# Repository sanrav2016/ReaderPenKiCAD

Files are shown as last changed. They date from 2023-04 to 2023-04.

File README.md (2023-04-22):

# ReaderPen KiCAD

KiCAD files for Reader Pen project. Manufacturing files for the PCB can be found here: https://github.com/sanrav2016/ReaderPenPCB.

Image of the schematic:


Some notes:
- We are using the STM32H723 microcontroller. STM is a reputable microcontroller manufacturer that dominates the commercial embedded systems market. This particular model belongs to their high-performance MCU series. The STM32H723 has a Cortex M7, and the VET6 package can run at 550MHz with 1 M flash and 564 K RAM. We have included an external 50 MHz clock. 
- We are using the TP4056 for microUSB charge control for a 3.7V 1000mAh LiPo battery.
- RGB LED for status indication
- Scan LEDs to highlight paper when reading
- The camera module in this system is the Himax HM01B0. It will not be ordered as we already have it at home from the Arducam module. A 2.8V LDO is necessarily included. 
- SWD for programming
- TRRS audio jack for speaker and mic (ADC/DAC). For simplicity no DSP is implemented.

The system will be programmed through STM32CubeIDE. Currently we are planning on using the C distributions of Tesseract and espeak, while implementing manual image processing. A demo of this concept can be found here: https://github.com/sanrav2016/ReaderPenRPiDemo.

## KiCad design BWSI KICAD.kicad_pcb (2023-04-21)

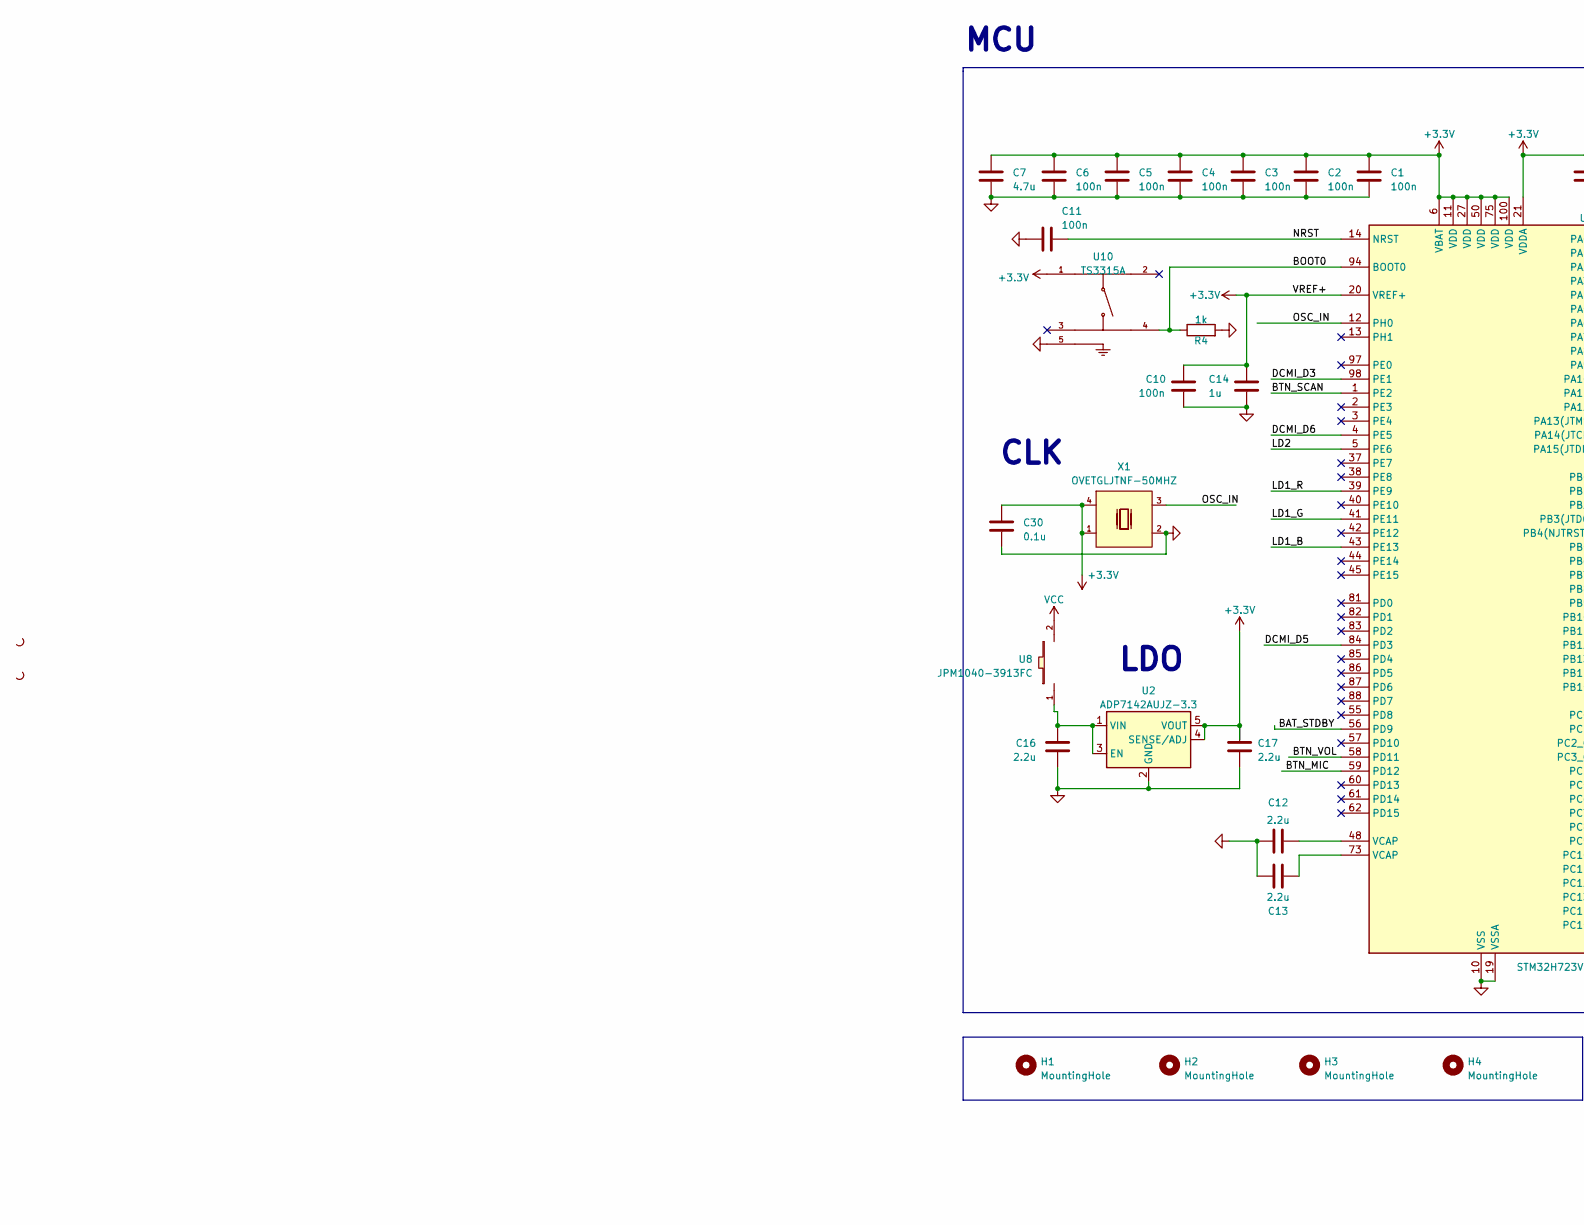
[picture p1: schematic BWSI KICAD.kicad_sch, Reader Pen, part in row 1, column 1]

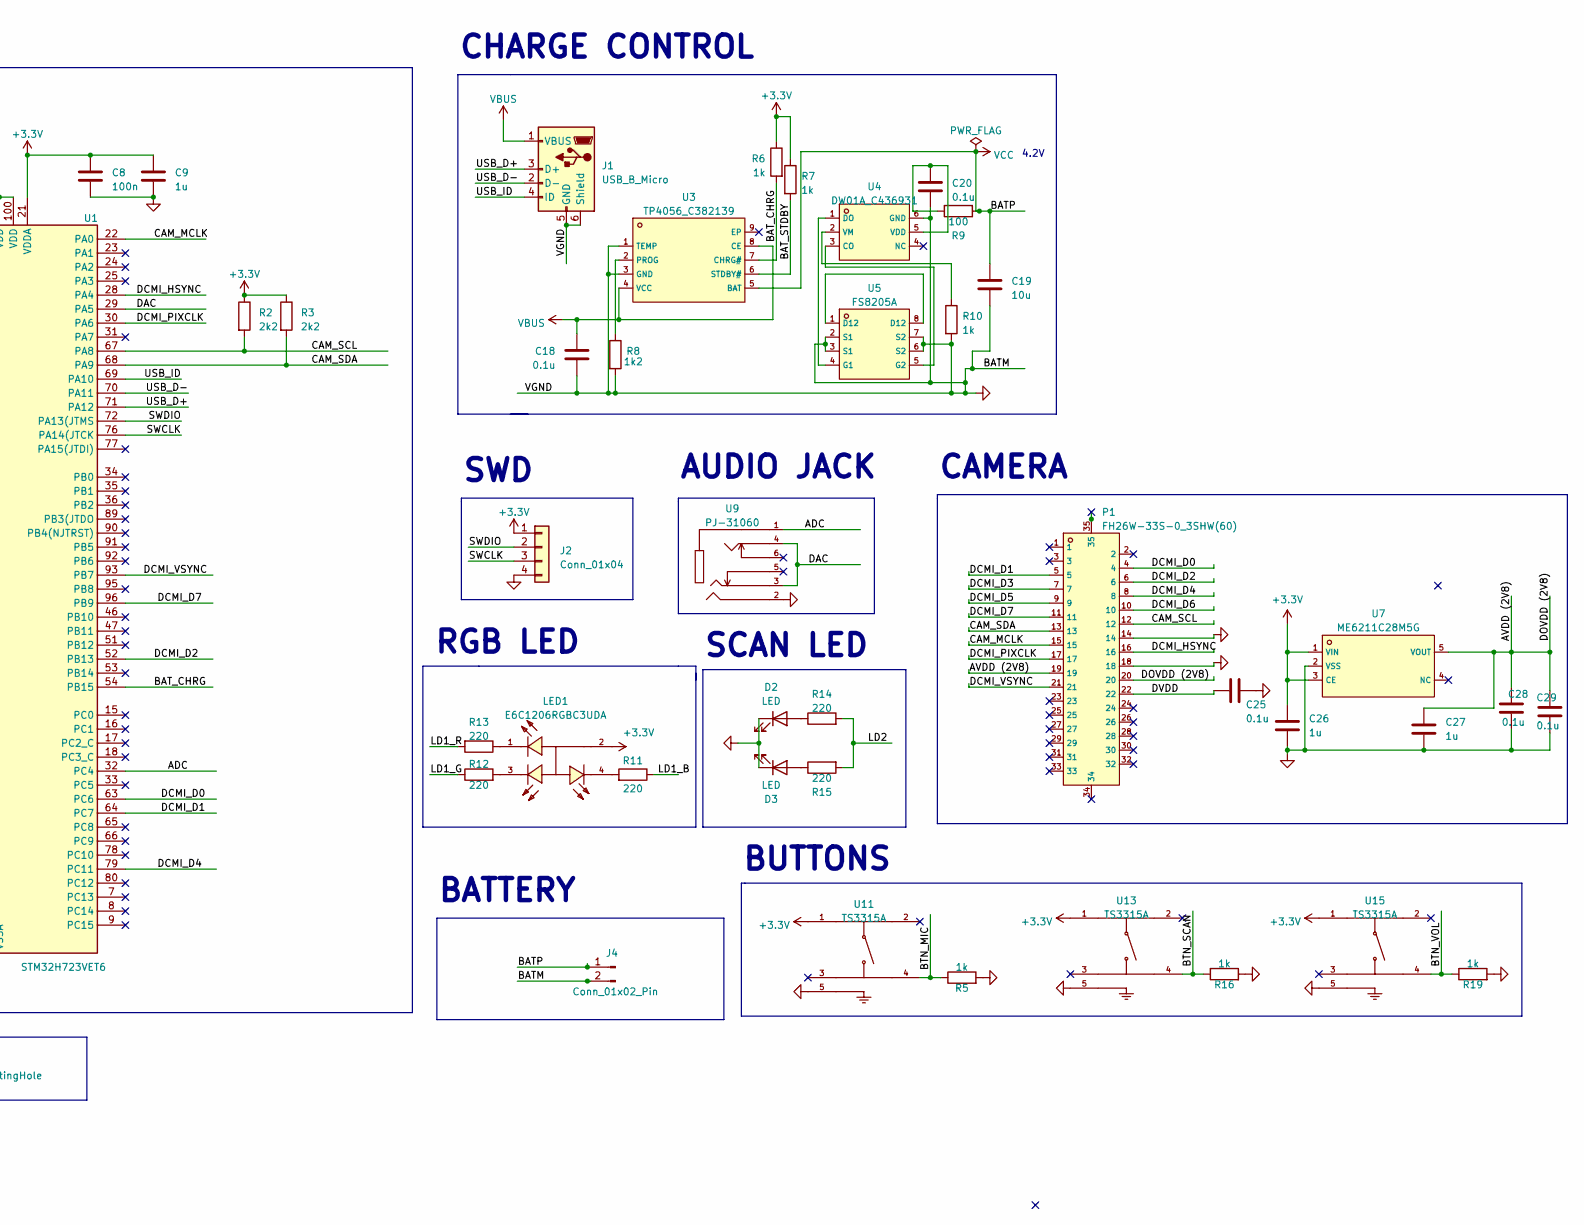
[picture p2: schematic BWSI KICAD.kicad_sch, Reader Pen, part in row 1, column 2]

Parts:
C1, C2, C3, C4, C5, C6, C8, C10, C11: 100n; C_0402_1005Metric
C7: 4.7u; C_0402_1005Metric
C9, C14, C26, C27: 1u; C_0402_1005Metric
C12, C13, C16, C17: 2.2u; C_0402_1005Metric
C18, C20, C25, C28, C29, C30: 0.1u; C_0402_1005Metric
C19: 10u; C_0402_1005Metric
D2, D3: LED; LED_0805_2012Metric
H1, H2, H3, H4: MountingHole; MountingHole_2.2mm_M2
J1: USB_B_Micro; USB_Micro-B_Molex_47346-0001
J2: Conn_01x04; SolderWire-0.25sqmm_1x04_P4.2mm_D0.65mm_OD1.7mm
J4: Conn_01x02_Pin; SolderWire-0.25sqmm_1x02_P4.2mm_D0.65mm_OD1.7mm
LED1: E6C1206RGBC3UDA; LED-SMD_4P-L3.0-W1.5-TL-FD; LCSC C375571
P1: FH26W-33S-0_3SHW(60); FPC-SMD_FH26W-33S-0.3SHW-60; LCSC C424654
R2, R3: 2k2; R_0402_1005Metric
R4, R5, R6, R7, R10, R16, R19: 1k; R_0402_1005Metric
R8: 1k2; R_0402_1005Metric
R9: 100; R_0402_1005Metric
R11, R12, R13, R14, R15: 220; R_0402_1005Metric
U1: STM32H723VET6; LQFP-100_14x14mm_P0.5mm
U2: ADP7142AUJZ-3.3; TSOT-23-5
U3: TP4056_C382139; ESOP-8_L4.9-W3.9-P1.27-LS6.0-BL-EP; LCSC C382139
U4: DW01A_C436931; SOT-23-6_L2.9-W1.6-P0.95-LS2.8-BL; LCSC C436931
U5: FS8205A; TSSOP-8_L4.4-W3.0-P0.65-LS6.4-BL-2; LCSC C16052
U7: ME6211C28M5G; SOT-23-5_L3.0-W1.7-P0.95-LS2.8-BR; LCSC C53099
U8: JPM1040-3913FC; SW-SMD_SMK_JPM1040-XXXXFC; LCSC C516063
U9: PJ-31060; AUDIO-SMD_HOOYA_PJ-31060; LCSC C2939583
U10, U11, U13, U15: TS3315A; SW-SMD_4P-L3.4-W3.4-P2.00-LS4.0_TS3315A160GF; LCSC C412367
X1: OVETGLJTNF-50MHZ; OSC-SMD_4P-L5.0-W3.2-BL_SG5032; LCSC C117891

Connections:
+3.3V: C1.1, C2.1, C3.1, C4.1, C5.1, C6.1, C7.1, C8.1, C9.1, C10.1, C14.1, C17.1, C26.1, C30.1, J2.1, LED1.2 (+), R2.1, R3.1, R6.1, R7.1, U1.6 (VBAT), U1.11 (VDD), U1.20 (VREF+), U1.21 (VDDA), U1.27 (VDD), U1.50 (VDD), U1.75 (VDD), U1.100 (VDD), U2.4 (SENSE/ADJ), U2.5 (VOUT), U7.1 (VIN), U7.3 (CE), U10.1 (A), U11.1 (A), U13.1 (A), U15.1 (A), X1.1 (tri), X1.4 (VCC)
/ADC: U1.32 (PC4), U9.1
/AVDD (2V8): C27.1, C28.1, C29.2, P1.19, P1.20, U7.5 (VOUT)
/BAT_CHRG: R6.2, U1.54 (PB15), U3.7 (CHRG#)
/BAT_STDBY: R7.2, U1.56 (PD9), U3.6 (STDBY#)
/BOOT0: R4.1, U1.94 (BOOT0), U10.4 (D)
/BTN_MIC: R5.1, U1.59 (PD12), U11.4 (D)
/BTN_SCAN: R16.1, U1.1 (PE2), U13.4 (D)
/BTN_VOL: R19.1, U1.58 (PD11), U15.4 (D)
/CAM_MCLK: P1.15, U1.22 (PA0)
/CAM_SCL: P1.12, R2.2, U1.67 (PA8)
/CAM_SDA: P1.13, R3.2, U1.68 (PA9)
/DAC: U1.29 (PA5), U9.3, U9.4
/DCMI_D0: P1.4, U1.63 (PC6)
/DCMI_D1: P1.5, U1.64 (PC7)
/DCMI_D2: P1.6, U1.52 (PB13)
/DCMI_D3: P1.7, U1.98 (PE1)
/DCMI_D4: P1.8, U1.79 (PC11)
/DCMI_D5: P1.9, U1.84 (PD3)
/DCMI_D6: P1.10, U1.4 (PE5)
/DCMI_D7: P1.11, U1.96 (PB9)
/DCMI_HSYNC: P1.16, U1.28 (PA4)
/DCMI_PIXCLK: P1.17, U1.30 (PA6)
/DCMI_VSYNC: P1.21, U1.93 (PB7)
/DVDD: C25.2, P1.22
/LD1_B: R11.1, U1.43 (PE13)
/LD1_G: R12.1, U1.41 (PE11)
/LD1_R: R13.2, U1.39 (PE9)
/LD2: R14.2, R15.2, U1.5 (PE6)
/NRST: C11.1, U1.14 (NRST)
/OSC_IN: U1.12 (PH0), X1.3 (OUT)
/SWCLK: J2.3, U1.76 (PA14(JTCK)
/SWDIO: J2.2, U1.72 (PA13(JTMS)
/USB_D+: J1.3 (D+), U1.71 (PA12)
/USB_D-: J1.2 (D-), U1.70 (PA11)
/USB_ID: J1.4 (ID), U1.69 (PA10)
GND: C1.2, C2.2, C3.2, C4.2, C5.2, C6.2, C7.2, C8.2, C9.2, C10.2, C11.2, C12.1, C13.1, C14.2, C16.2, C17.2, C18.2, C19.2, C20.2, C25.1, C26.2, C27.2, C28.2, C29.1, C30.2, D2.1 (K), D3.1 (K), J1.5 (GND), J1.6 (Shield), J2.4, J4.2, P1.14, P1.18, R4.2, R5.2, R8.2, R10.2, R16.2, R19.2, U1.10 (VSS), U1.19 (VSSA), U1.26 (VSS), U1.49 (VSS), U1.74 (VSS), U1.99 (VSS), U2.2 (GND), U3.1 (TEMP), U3.3 (GND), U4.6 (GND), U5.2 (S1), U5.3 (S1), U5.6 (S2), U5.7 (S2), U7.2 (VSS), U9.2, U10.5 (GND), U11.5 (GND), U13.5 (GND), U15.5 (GND), X1.2 (GND)
unnamed: C12.2, U1.48 (VCAP)
unnamed: C13.2, U1.73 (VCAP)
unnamed: D2.2 (A), R14.1
unnamed: D3.2 (A), R15.1
unnamed: LED1.1 (-), R13.1
unnamed: LED1.3 (-), R12.2
unnamed: LED1.4 (-), R11.2
unnamed: C16.1, U2.1 (VIN), U2.3 (EN), U8.1
unnamed: R8.1, U3.2 (PROG)
unnamed: U4.3 (CO), U5.5 (G2)
unnamed: U4.1 (DO), U5.4 (G1)
unnamed: C20.1, R9.1, U4.5 (VDD)
unnamed: R10.1, U4.2 (VM)
unnamed: U5.1 (D12), U5.8 (D12)
VBUS: C18.1, J1.1 (VBUS), U3.4 (VCC), U3.8 (CE)
VCC: C19.1, J4.1, R9.2, U3.5 (BAT), U8.2

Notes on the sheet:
CAMERA
SCAN LED
AUDIO JACK
LDO
BUTTONS
CHARGE CONTROL
RGB LED
4.2V
CLK
SWD
BATTERY
MCU

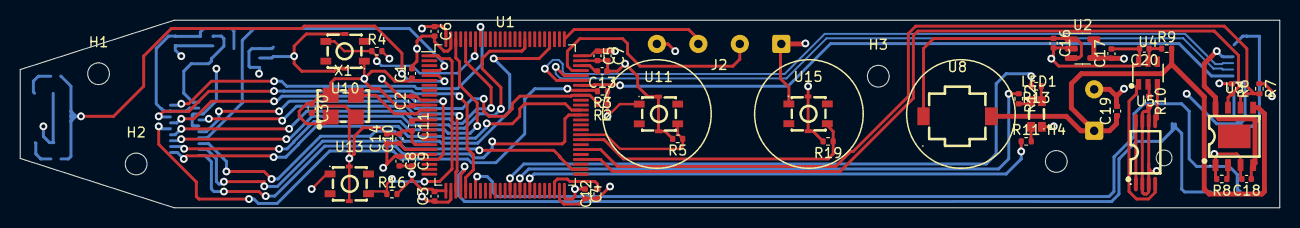
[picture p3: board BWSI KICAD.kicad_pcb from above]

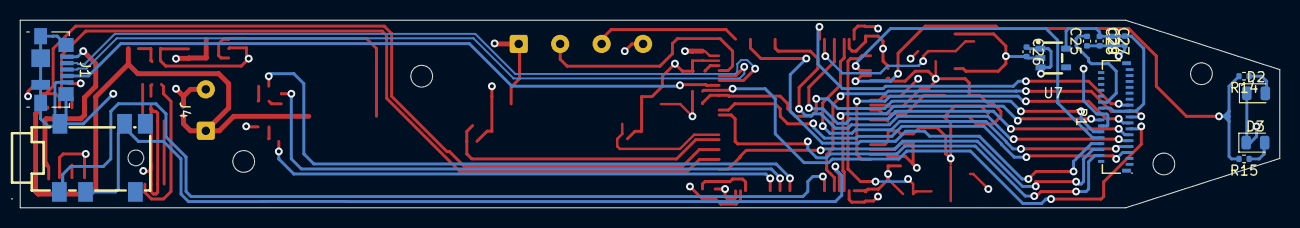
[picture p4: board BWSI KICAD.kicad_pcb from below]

Board: 4 copper layers, 127.6 x 19.0 mm, 65 parts (14 on the bottom side), 53 nets.
